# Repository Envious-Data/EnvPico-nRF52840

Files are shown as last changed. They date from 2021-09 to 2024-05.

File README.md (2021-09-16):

# EnvOpenPico
A nRF52840 MCU board that is in the size of a raspberry pi pico.

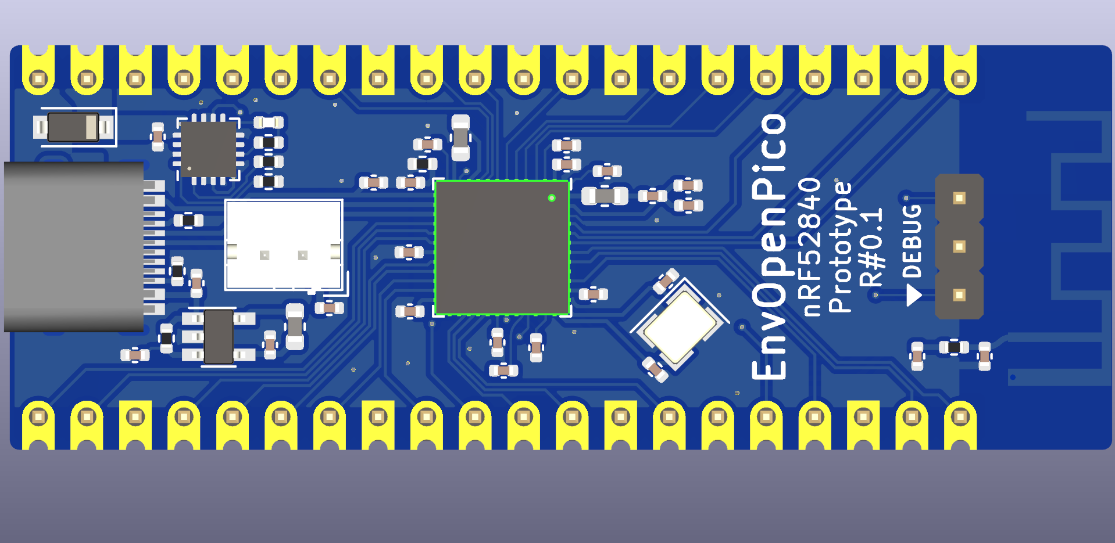
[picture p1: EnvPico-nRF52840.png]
Board image


### Info
like the other boards Ive designed, I wanted to make sure this would fit in place of a raspberry pi pico incase you wanted wifi + bluetooth and battery on one board instead of a stack of packs for the pi pico.

this is intended to be used with my keyboards again like the other boards but ive made sure to include a decently powerful PMIC just so its capable of other things too, the BQ24072RGT should be capable of upto 1.5A output but around 500mA charging.

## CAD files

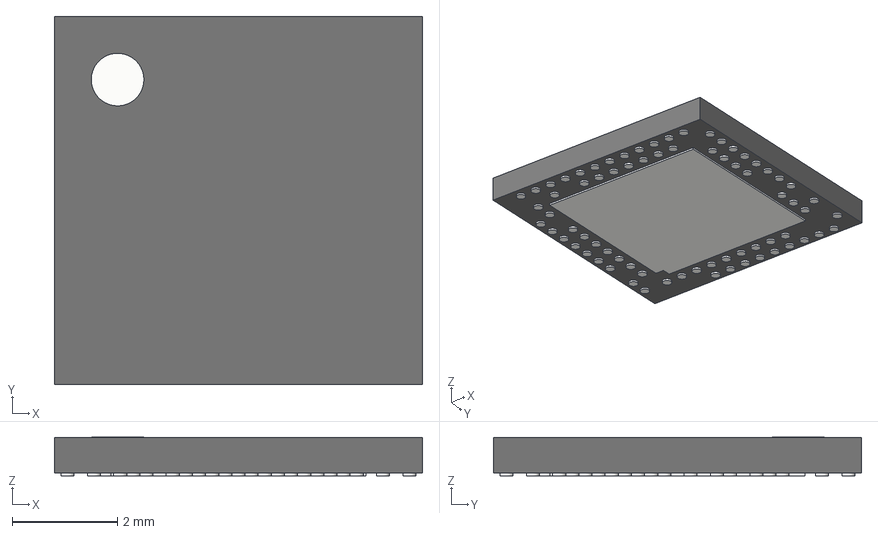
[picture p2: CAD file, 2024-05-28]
PCB-Variant-A/Resources/nRF-aQFN73.step
7.00 x 7.00 x 0.735 mm

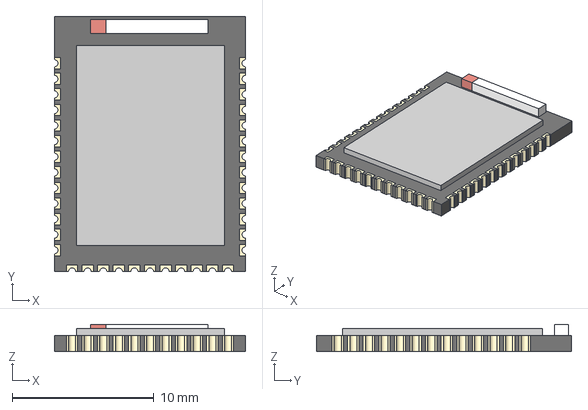
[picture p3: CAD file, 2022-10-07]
PCB-Variant-B/Resources/holyiot-18010.step
13.5 x 18.0 x 1.92 mm

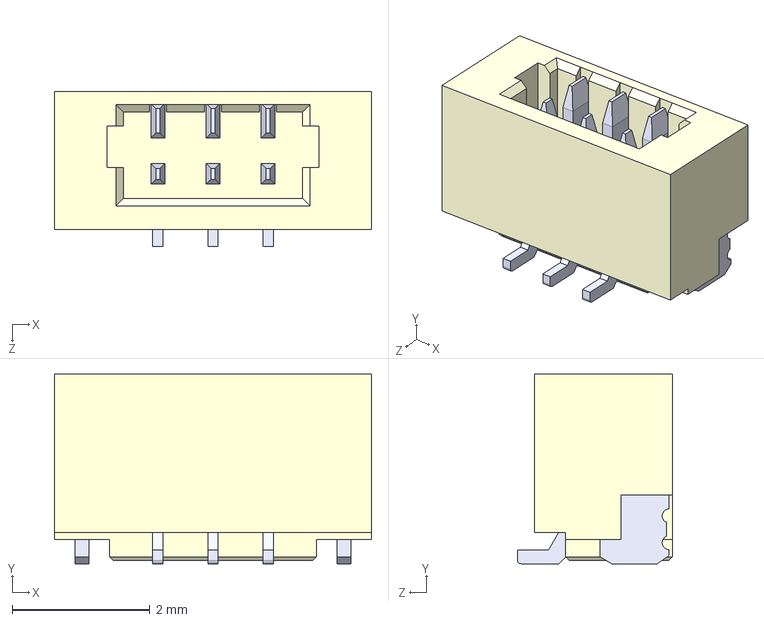
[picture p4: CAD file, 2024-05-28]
PCB-Variant-A/Resources/BM03B.STEP
4.60 x 2.75 x 2.25 mm

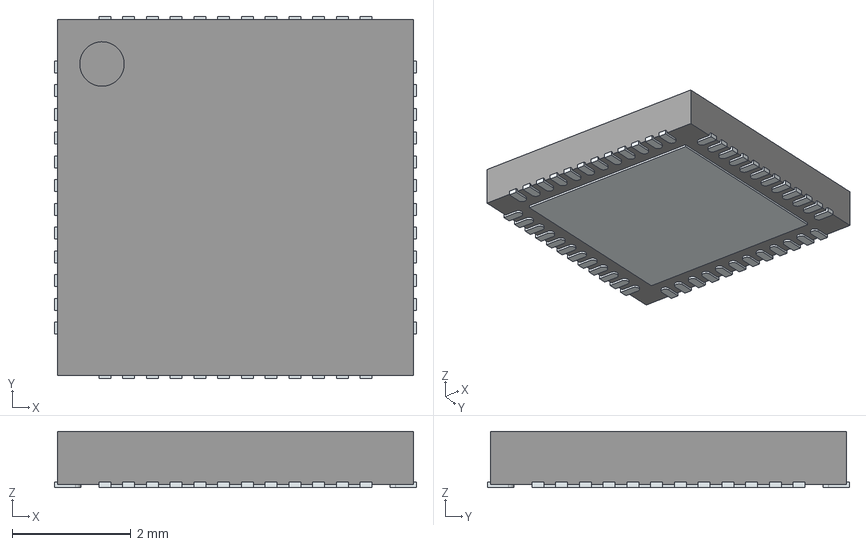
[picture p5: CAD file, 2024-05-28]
PCB-Variant-A/Resources/nRF52840-QFAA-F-R7/nRF52840-QFAA-F-R7.stp
6.10 x 6.10 x 0.95 mm
ThermalPin
PinsArrayLR
PinsArrayTB

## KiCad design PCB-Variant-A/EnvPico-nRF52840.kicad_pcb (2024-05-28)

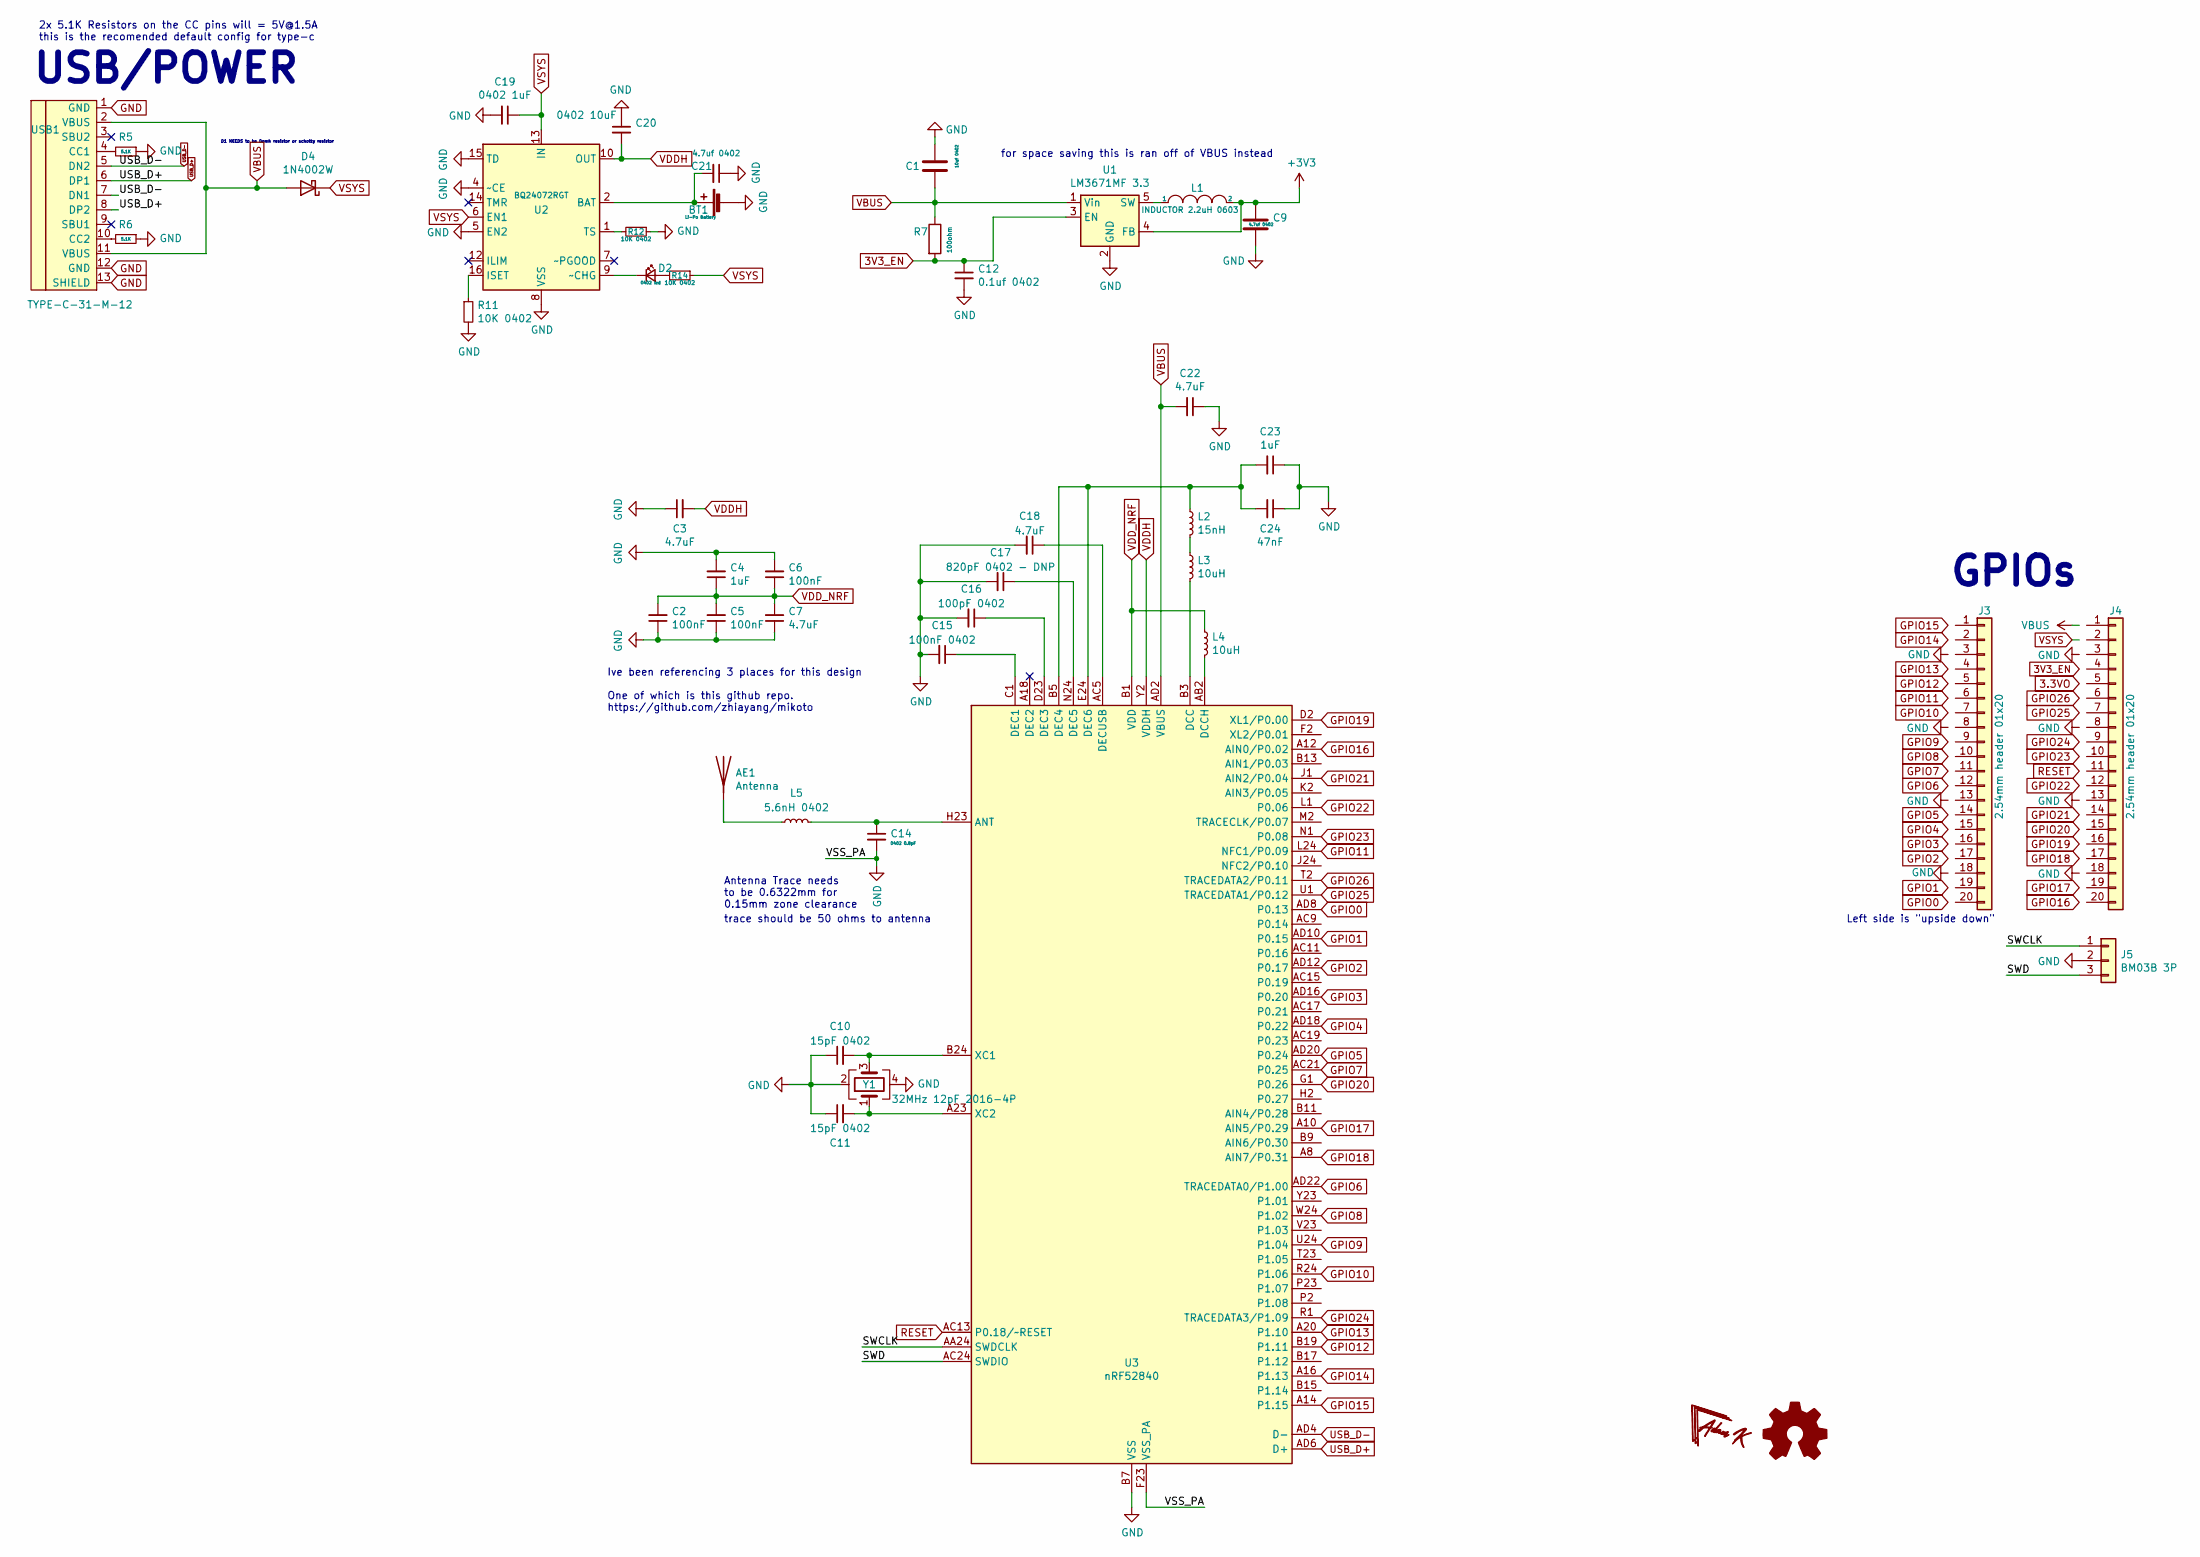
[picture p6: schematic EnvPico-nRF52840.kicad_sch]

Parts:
AE1: Antenna; Johanson_2450AT43F0100
BT1: Li-Po Battery; JST_PH_B2B-PH-K_1x02_P2.00mm_Vertical
C1: 10uf 0402; C_0402_1005Metric
C2, C5, C6: 100nF; C_0402_1005Metric; Manufacturer Part CL05B104KA5NNNC; LCSC Part C1525
C3, C7, C18, C22: 4.7uF; C_0402_1005Metric; Manufacturer Part CL05A475KP5NRNC; LCSC Part C368809
C4, C23: 1uF; C_0402_1005Metric; Manufacturer Part CL05A105KO5NNNC; LCSC Part C52923
C9, C21: 4.7uf 0402; C_0402_1005Metric
C10, C11: 15pF 0402; C_0402_1005Metric
C12: 0.1uf 0402; C_0402_1005Metric
C14: 0402 0.8pF; C_0402_1005Metric
C15: 100nF 0402; C_0402_1005Metric; Manufacturer Part CL05B104KA5NNNC; LCSC Part C1525
C16: 100pF 0402; C_0402_1005Metric; Manufacturer Part CL05C101JB5NNNC; LCSC Part C26409
C17: 820pF 0402 - DNP; C_0402_1005Metric; Manufacturer Part CL05B102KB5NNNC; LCSC Part C14442
C19: 0402 1uF; C_0402_1005Metric
C20: 0402 10uF; R_0402_1005Metric
C24: 47nF; C_0402_1005Metric; Manufacturer Part CL05B473KO5NNNC; LCSC Part C307434
D2: 0402 led; LED_0402_1005Metric
D4: 1N4002W; D_SOD-123
J3, J4: 2.54mm header 01x20; PinHeader_1x20_P2.54mm_Vertical_castelated
J5: BM03B 3P; JST_SUR_BM03B-SURS-TF_1x03-1MP_P0.80mm_Vertical
L1: INDUCTOR 2.2uH 0603; L_0603_1608Metric
L2: 15nH; C_0402_1005Metric; Manufacturer Part MLG1005S15NJT000; LCSC Part C76763
L3, L4: 10uH; L_0603_1608Metric; Manufacturer Part MLF1608E100KTD00; LCSC Part C76732
L5: 5.6nH 0402; L_0402_1005Metric
R5, R6: 5.1K; R_0402_1005Metric
R7: 100ohm; R_0402_1005Metric
R11, R12, R14: 10K 0402; R_0402_1005Metric
U1: LM3671MF 3.3; TSOT-23-5
U2: BQ24072RGT; VQFN-16-1EP_3x3mm_P0.5mm_EP1.6x1.6mm
U3: nRF52840; Nordic_AQFN-73-1EP_7x7mm_P0.5mm
USB1: TYPE-C-31-M-12; HRO-TYPE-C-31-M-12
Y1: 32MHz 12pF 2016-4P; Crystal_SMD_2016-4Pin_2.0x1.6mm

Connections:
3V3_EN: C12.1, R7.2, U1.3 (EN)
+3V3: C9.1, L1.2, U1.4 (FB)
/SWCLK: J5.1, U3.AA24 (SWDCLK)
/SWD: J5.3, U3.AC24 (SWDIO)
GND: BT1.2 (-), C1.2, C2.1, C3.1, C4.2, C5.1, C6.2, C7.1, C9.2, C10.1, C11.1, C12.2, C14.2, C15.2, C16.2, C17.2, C18.2, C19.2, C20.1, C21.1, C22.1, C23.1, C24.1, J5.2, R5.1, R6.1, R11.2, R12.1, U1.2 (GND), U2.4 (~CE), U2.5 (EN2), U2.8 (VSS), U2.15 (TD), U2.17 (VSS), U3.B7 (VSS), U3.EP (VSS), U3.F23 (VSS_PA), USB1.1 (GND), USB1.12 (GND), USB1.13 (SHIELD), Y1.2, Y1.4
GPIO0: U3.AD8 (P0.13)
GPIO1: U3.AD10 (P0.15)
GPIO2: U3.AD12 (P0.17)
GPIO3: U3.AD16 (P0.20)
GPIO4: U3.AD18 (P0.22)
GPIO5: U3.AD20 (P0.24)
GPIO6: U3.AD22 (TRACEDATA0/P1.00)
GPIO7: U3.AC21 (P0.25)
GPIO8: U3.W24 (P1.02)
GPIO9: U3.U24 (P1.04)
GPIO10: U3.R24 (P1.06)
GPIO11: U3.L24 (NFC1/P0.09)
GPIO12: U3.B19 (P1.11)
GPIO13: U3.A20 (P1.10)
GPIO14: U3.A16 (P1.13)
GPIO15: U3.A14 (P1.15)
GPIO16: U3.A12 (AIN0/P0.02)
GPIO17: U3.A10 (AIN5/P0.29)
GPIO18: U3.A8 (AIN7/P0.31)
GPIO19: U3.D2 (XL1/P0.00)
GPIO20: U3.G1 (P0.26)
GPIO21: U3.J1 (AIN2/P0.04)
GPIO22: U3.L1 (P0.06)
GPIO23: U3.N1 (P0.08)
GPIO24: U3.R1 (TRACEDATA3/P1.09)
GPIO25: U3.U1 (TRACEDATA1/P0.12)
GPIO26: U3.T2 (TRACEDATA2/P0.11)
unnamed: AE1.1 (A), L5.1
unnamed: BT1.1 (+), C21.2, U2.2 (BAT), U2.3 (BAT)
unnamed: D2.2 (A), R14.2
unnamed: D2.1 (K), U2.9 (~CHG)
unnamed: L2.2, L3.1
unnamed: L1.1, U1.5 (SW)
unnamed: R11.1, U2.16 (ISET)
unnamed: R12.2, U2.1 (TS)
unnamed: C14.1, L5.2, U3.H23 (ANT)
unnamed: L3.2, U3.B3 (DCC)
unnamed: L4.2, U3.AB2 (DCCH)
unnamed: C15.1, U3.C1 (DEC1)
unnamed: C16.1, U3.D23 (DEC3)
unnamed: C23.2, C24.2, L2.1, U3.B5 (DEC4), U3.E24 (DEC6)
unnamed: C17.1, U3.N24 (DEC5)
unnamed: C18.1, U3.AC5 (DECUSB)
unnamed: C10.2, U3.B24 (XC1), Y1.3
unnamed: C11.2, U3.A23 (XC2), Y1.1
unnamed: R5.2, USB1.4 (CC1)
unnamed: R6.2, USB1.10 (CC2)
RESET: U3.AC13 (P0.18/~RESET)
USB_D+: U3.AD6 (D+), USB1.6 (DP1), USB1.8 (DP2)
USB_D-: U3.AD4 (D-), USB1.5 (DN2), USB1.7 (DN1)
VBUS: C1.1, C22.2, D4.2 (A), R7.1, U1.1 (Vin), U3.AD2 (VBUS), USB1.2 (VBUS), USB1.11 (VBUS)
VDDH: C3.2, C20.2, U2.10 (OUT), U2.11 (OUT), U3.Y2 (VDDH)
VDD_NRF: C2.2, C4.1, C5.2, C6.1, C7.2, L4.1, U3.A22 (VDD), U3.AD14 (VDD), U3.AD23 (VDD), U3.B1 (VDD), U3.W1 (VDD)
VSYS: C19.1, D4.1 (K), R14.1, U2.6 (EN1), U2.13 (IN)

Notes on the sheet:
Ive been referencing 3 places for this design One of which is this github repo. https://github.com/zhiayang/mikoto
D1 NEEDS to be 0omh resistor or schotky resistor
2x 5.1K Resistors on the CC pins will = 5V@1.5A this is the recomended default config for type-c
Antenna Trace needs to be 0.6322mm for 0.15mm zone clearance
USB/POWER
GPIOs
trace should be 50 ohms to antenna
for space saving this is ran off of VBUS instead
Left side is "upside down"

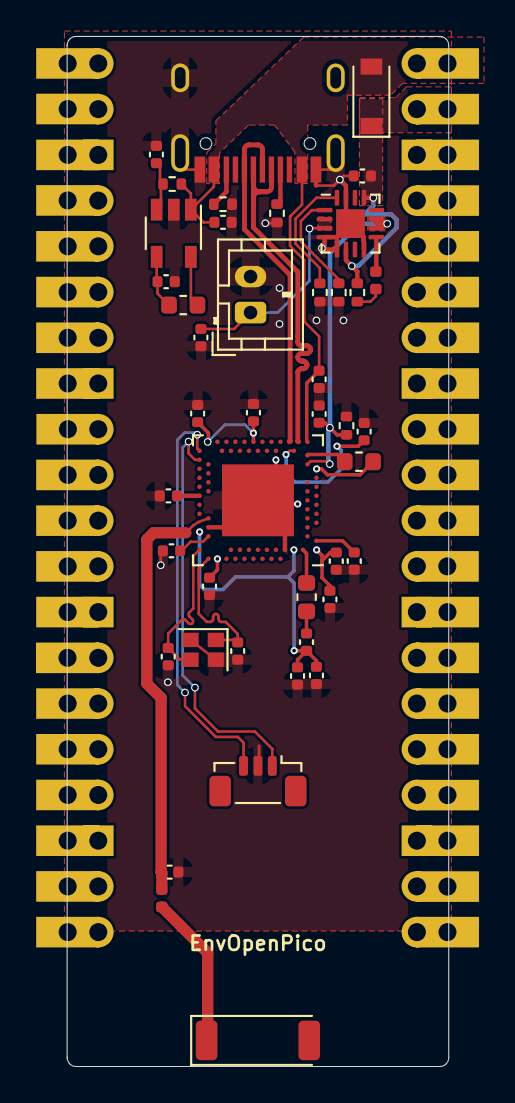
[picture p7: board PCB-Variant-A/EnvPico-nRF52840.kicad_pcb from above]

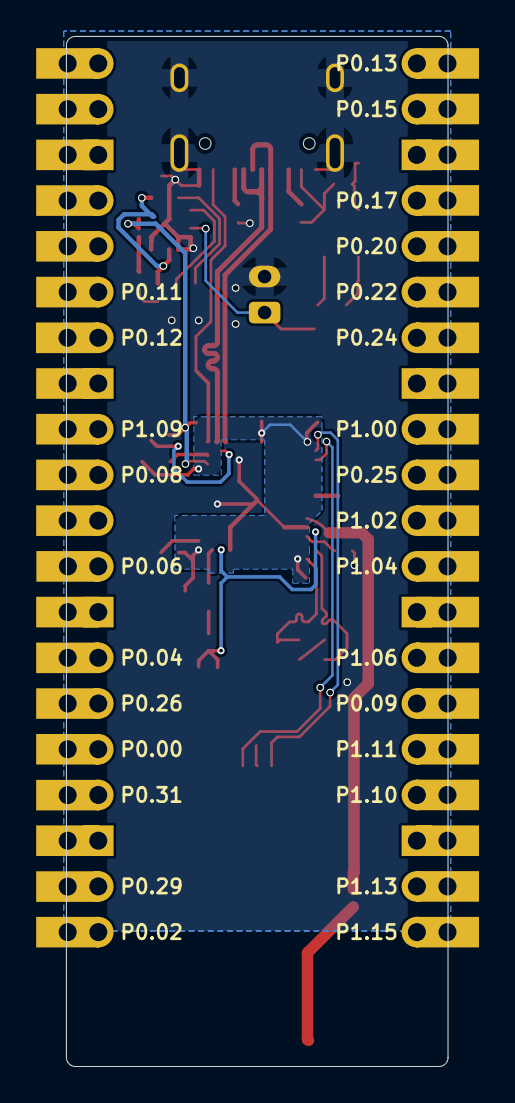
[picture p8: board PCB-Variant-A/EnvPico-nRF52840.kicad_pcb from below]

Board: 2 copper layers, 21.2 x 57.2 mm, 45 parts (2 on the bottom side), 31 nets.

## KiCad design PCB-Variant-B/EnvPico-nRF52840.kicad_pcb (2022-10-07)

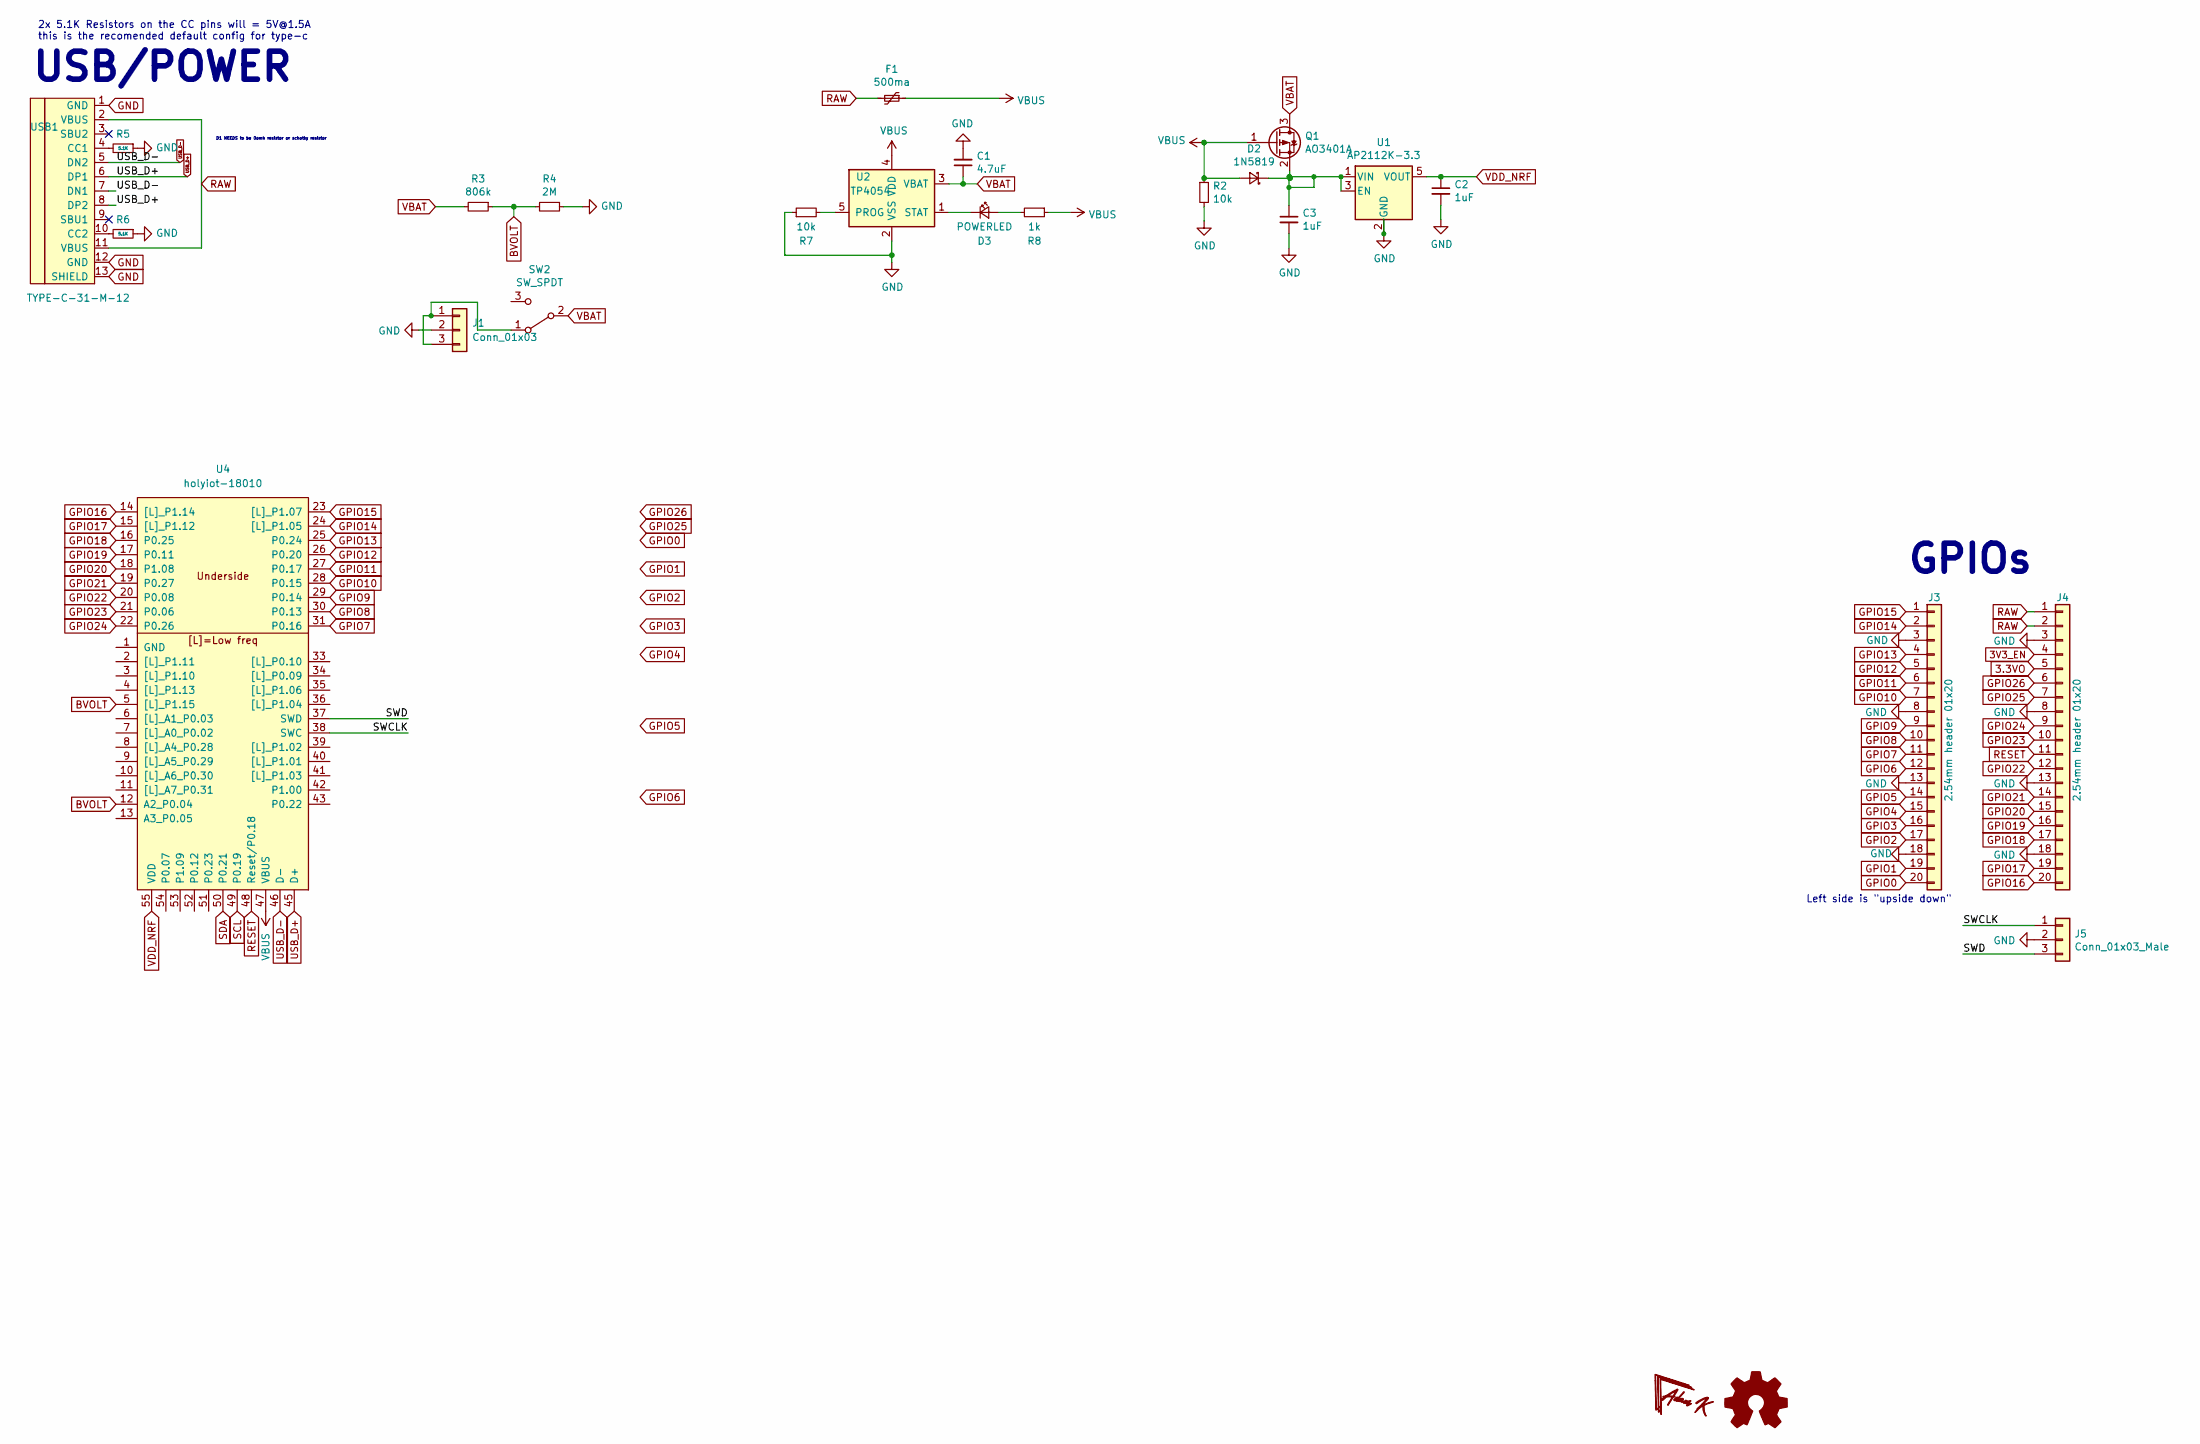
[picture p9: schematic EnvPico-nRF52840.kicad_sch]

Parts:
C1: 4.7uF; C_0402_1005Metric
C2, C3: 1uF; C_0402_1005Metric
D2: 1N5819; D_SOD-123
D3: POWERLED; D_0402_1005Metric
F1: 500ma; Fuse_0805_2012Metric
J1: Conn_01x03; JST_SH_BM03B-SRSS-TB_1x03-1MP_P1.00mm_Vertical
J3, J4: 2.54mm header 01x20; PinHeader_1x20_P2.54mm_Vertical_castelated
J5: Conn_01x03_Male; PinHeader_1x03_P2.54mm_Vertical
Q1: AO3401A; SOT-23
R2, R7: 10k; R_0402_1005Metric
R3: 806k; R_0402_1005Metric
R4: 2M; R_0402_1005Metric
R5, R6: 5.1K; R_0402_1005Metric
R8: 1k; R_0402_1005Metric
SW2: SW_SPDT; PinHeader_1x03_P1.00mm_Vertical
U1: AP2112K-3.3; SOT-23-5
U2: TP4054; SOT-23-5
U4: holyiot-18010
USB1: TYPE-C-31-M-12; HRO-TYPE-C-31-M-12

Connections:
3.3VO: J4.5
3V3_EN: J4.4
/SWCLK: J5.1, U4.38 (SWC)
/SWD: J5.3, U4.37 (SWD)
BVOLT: R3.1, R4.2, U4.5 ([L]_P1.15), U4.12 (A2_P0.04)
GPIO0: J3.20
GPIO1: J3.19
GPIO2: J3.17
GPIO3: J3.16
GPIO4: J3.15
GPIO5: J3.14
GPIO6: J3.12
GPIO7: J3.11, U4.31 (P0.16)
GPIO8: J3.10, U4.30 (P0.13)
GPIO9: J3.9, U4.29 (P0.14)
GPIO10: J3.7, U4.28 (P0.15)
GPIO11: J3.6, U4.27 (P0.17)
GPIO12: J3.5, U4.26 (P0.20)
GPIO13: J3.4, U4.25 (P0.24)
GPIO14: J3.2, U4.24 ([L]_P1.05)
GPIO15: J3.1, U4.23 ([L]_P1.07)
GPIO16: J4.20, U4.14 ([L]_P1.14)
GPIO17: J4.19, U4.15 ([L]_P1.12)
GPIO18: J4.17, U4.16 (P0.25)
GPIO19: J4.16, U4.17 (P0.11)
GPIO20: J4.15, U4.18 (P1.08)
GPIO21: J4.14, U4.19 (P0.27)
GPIO22: J4.12, U4.20 (P0.08)
GPIO23: J4.10, U4.21 (P0.06)
GPIO24: J4.9, U4.22 (P0.26)
GPIO25: J4.7
GPIO26: J4.6
unnamed: C3.1, D2.1 (K), Q1.2 (S), U1.1 (VIN), U1.3 (EN)
unnamed: D3.1 (K), U2.1 (STAT)
unnamed: D3.2 (A), R8.2
unnamed: J1.1, J1.3, SW2.1 (A)
unnamed: R5.2, USB1.4 (CC1)
unnamed: R6.2, USB1.10 (CC2)
unnamed: R7.2, U2.5 (PROG)
RAW: F1.2, J4.1, J4.2, USB1.2 (VBUS), USB1.11 (VBUS)
RESET: J4.11, U4.48 (Reset/P0.18)
SCL: U4.49 (P0.19)
SDA: U4.50 (P0.21)
USB_D+: U4.45 (D+), USB1.6 (DP1), USB1.8 (DP2)
USB_D-: U4.46 (D-), USB1.5 (DN2), USB1.7 (DN1)
VBAT: C1.1, Q1.3 (D), R3.2, SW2.2 (B), U2.3 (VBAT)
VBUS: D2.2 (A), F1.1, Q1.1 (G), R2.1, R8.1, U2.4 (VDD), U4.47 (VBUS)
VDD_NRF: C2.1, U1.5 (VOUT), U4.55 (VDD)

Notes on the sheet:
D1 NEEDS to be 0omh resistor or schotky resistor
2x 5.1K Resistors on the CC pins will = 5V@1.5A this is the recomended default config for type-c
USB/POWER
GPIOs
Left side is "upside down"

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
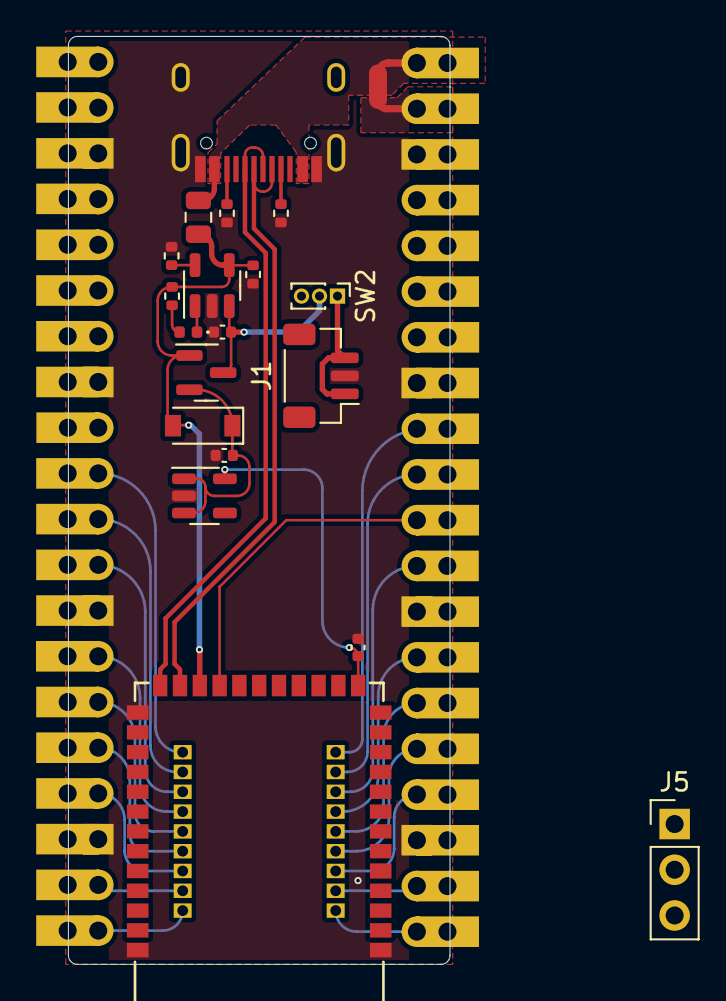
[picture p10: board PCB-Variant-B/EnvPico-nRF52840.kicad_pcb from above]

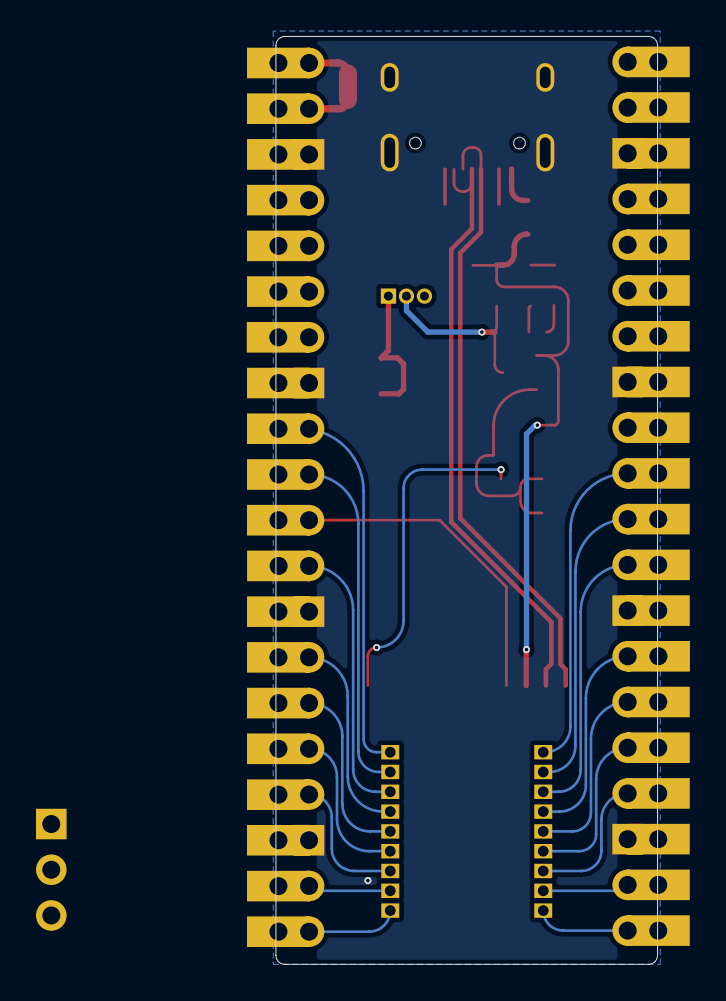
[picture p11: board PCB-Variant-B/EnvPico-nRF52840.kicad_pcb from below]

Board: 2 copper layers, 21.2 x 51.6 mm, 21 parts (2 on the bottom side), 36 nets.

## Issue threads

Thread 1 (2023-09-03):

WIZCUBE EnvPico-nRF52840 substitution

M10CUBE, 2023-09-03:
Hi ,
I am the creator of the community project M10CUBE and wizcube
https://gitlab.com/m10cube/m10
https://wizcube.eu.

I am in the process of making an nRF52840 module to fit on the Raspberry Pico footprint and came up your design.
Do you like to cooperate in designing a better EnvPico-nRF52840  ?
The idea is to have some power management on board and battery, RS485, MEMS microphone and an BME680 sensor among others.
That module will be drop in replacement for all wizcube modules plus an add on on a new M10CUBE CM4 + mobile module I am building.
If you are interested to explore the possibilities please contact
vorrias@pan-gaea.gr
Thank you
Vasilis

Envious-Data, 2023-09-05:
Hello

currently im busy with other projects but you are open to forking the NRF
pico, I think it has a battery manegement IC on there already but you'll
need to add the other things, keep in mind the design is already borderline
on JLCPCBs limits if thats your fab of choice so its possible it might end
up with lots of faulty units unless you plan to adjust it, the antenna also
needs to be properly tuned as this is something outside of my skill area, I
planned to come back at this project at some point but as said you are free
to fork and do what you wish.

Ive seen some people use those nrf52840 holyiot modules and it might be
possible to fit one onto a pico board and then wire up the GPIOs
eliminating the problems I encountered since it has its own antenna and
supporting circuitry besides power I believe.

- Adam

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

M10CUBE, 2023-09-05:
Hi Adam,
Nice hearing from you,

I am thinking of using the UBLOX module BMD-345.Many known like Arduino and
Sparkfun are using UBLOX nRF52840 modules
It has Extended range with PA + LNA. Antenna connector fro using it inside
a metal enclosure. We do not have to wary then about antenna design (not an
easy job)
Having that on board, design will be a piece of cake. It is widely
available on Mouser and about 14 euros.
Some more hardware I am thinking on board like battery and RS485.
We will be able to drop it into our www.wizcube.eu I/O module and have a
long range BLE mesh network with Zigbee, Mather and Thread on board
I can send it to JLCBCB for mash production. Bare PCB or populated with the
UBLOX
Then there is another reason.
I am designing an M10CUBE (wizcube) PCB 90x90 mm with nRF9160 LTE module on
board. On that board the UBLOX module BMD-345 module will be on board as
well for communication with the wizcube I/O modules with the Raspberry Pico
/ UBLOX BMD-345.
That way all the M10CUBE ecosystem will have a gateway to LTE, LTE-M.
NB-IOT, DECT NR+ communication.

What do you think?
I am open to ideas
Regards

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

--
Vasilis Vorrias

R&D Electronics and Automation
email: ***@***.***
linkedin.com/in/vasilis-vorrias-586805176
<https://www.linkedin.com/in/vasilis-vorrias-586805176>

M10CUBE project: https://gitlab.com/m10cube/m10

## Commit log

2021-08-14 Initial Commit +1
    [EnvPico-nRF52840.kicad_pcb, EnvPico-nRF52840.kicad_sch, EnvPico-nRF52840.sch]
2021-08-14 started adding some pins for GPIO
    [EnvPico-nRF52840.kicad_pcb, EnvPico-nRF52840.kicad_sch]
2021-08-14 made sure all vias are correctly placed and sized.
    [EnvPico-nRF52840.kicad_pcb]
2021-08-17 connected all 26 GPIOs among other things.
    [EnvPico-nRF52840.kicad_pcb, EnvPico-nRF52840.kicad_sch]
2021-08-23 changed 2012 crystal for a 3225 size due to part availability. + went through and did a general clean up and correction per DRC.
    [EnvPico-nRF52840.kicad_pcb, EnvPico-nRF52840.kicad_sch]
2021-08-23 generated upto date gerber, going to start putting money aside to order this PCB.
    [EnvPico-nRF52840.kicad_pcb]
2021-09-04 fixed a kicad derp
    [EnvPico-nRF52840.kicad_sch, EnvPico-nRF52840.sch]
2021-09-04 adjusted footprint of nRF52840 a bit, adjusted few traces and via locations.
    [EnvPico-nRF52840.kicad_pcb]
2021-09-04 moved some traces about to make sure there is good ground coverage
    [EnvPico-nRF52840.kicad_pcb, EnvPico-nRF52840.kicad_sch]
2021-09-05 fixed leftover silkscreen C12, couple of plane tweaks and added center marker / board dimensions on back of PCB, fixed incorrect diode footprint and in schematic
    [EnvPico-nRF52840.kicad_pcb, EnvPico-nRF52840.kicad_sch]
2021-09-16 some edits and corrections
    [EnvPico-nRF52840.kicad_pcb]
2021-09-16 added silkscreen pin labels to the bottom of the PCB
    [EnvPico-nRF52840.kicad_pcb, EnvPico-nRF52840.kicad_sch]
2022-01-26 Corrected Antenna stuff hopefully
    this is voodoo to me so its probably still wrong.
    [EnvPico-nRF52840.kicad_pcb]
2022-06-21 I think this is correct trace thickness for 50ohm impedance
    [EnvPico-nRF52840.kicad_pcb, EnvPico-nRF52840.kicad_sch]
2022-07-21 preperation to potentially make a module version
    [EnvPico-nRF52840.kicad_sch]
2022-10-07 made a couple of pcb variants for future use maybe
    [EnvPico-nRF52840.kicad_pcb, EnvPico-nRF52840.kicad_sch, EnvPico-nRF52840.sch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]
2024-05-28 added library for QFN version
    [EnvPico-nRF52840.kicad_pcb, EnvPico-nRF52840.kicad_sch, nRF52840-QFAA-F-R7.stp]
2024-05-28 started re-design of board.
    [BM03B.STEP, EnvPico-nRF52840.kicad_pcb, EnvPico-nRF52840.kicad_sch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]
